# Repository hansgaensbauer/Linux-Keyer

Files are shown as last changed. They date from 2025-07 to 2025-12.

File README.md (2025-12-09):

# Linux-Keyer
An automatic CW keyer build around the [SimpleSBC](https://github.com/hansgaensbauer/SimpleSBC).

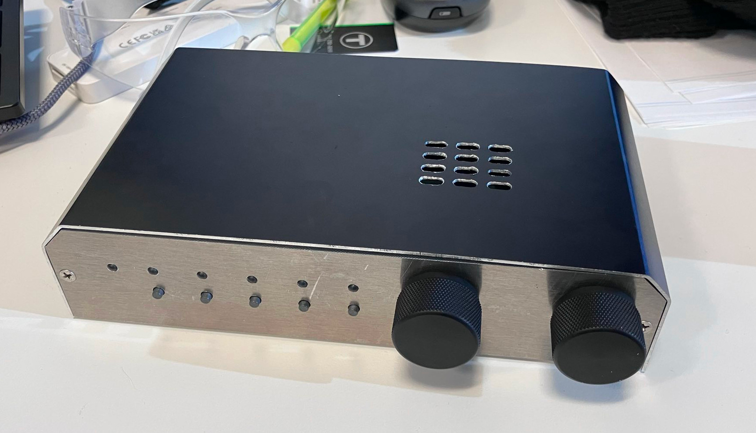
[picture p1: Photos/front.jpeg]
A photo of the keyer


## Features
- 2 Key/Paddle inputs (both keys and paddles supported on both inputs)
- Automatic detection of key wiring
- PTT and Key outputs
- Internal and external speaker support
- Network connectivity (10/100)
- Linux!

<table>
  <tr>
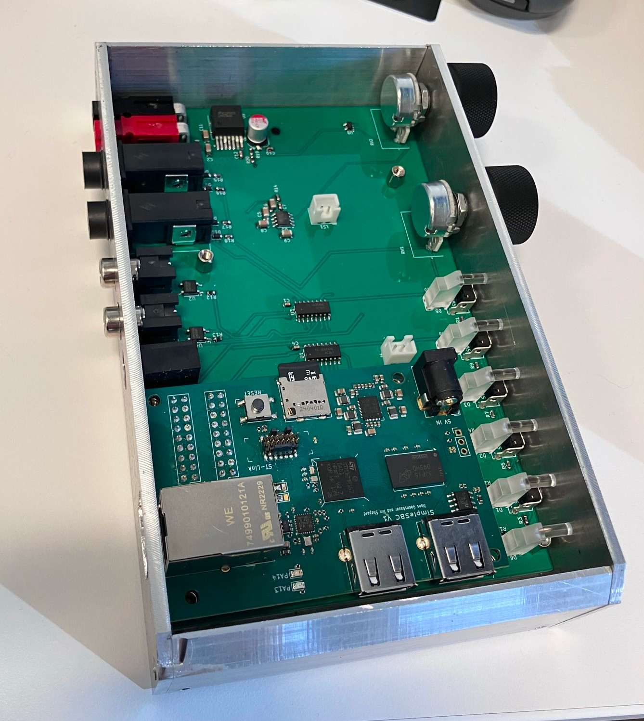
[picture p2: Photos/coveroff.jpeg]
The keyer with the cover off, showing the circuit board
    <td></td>
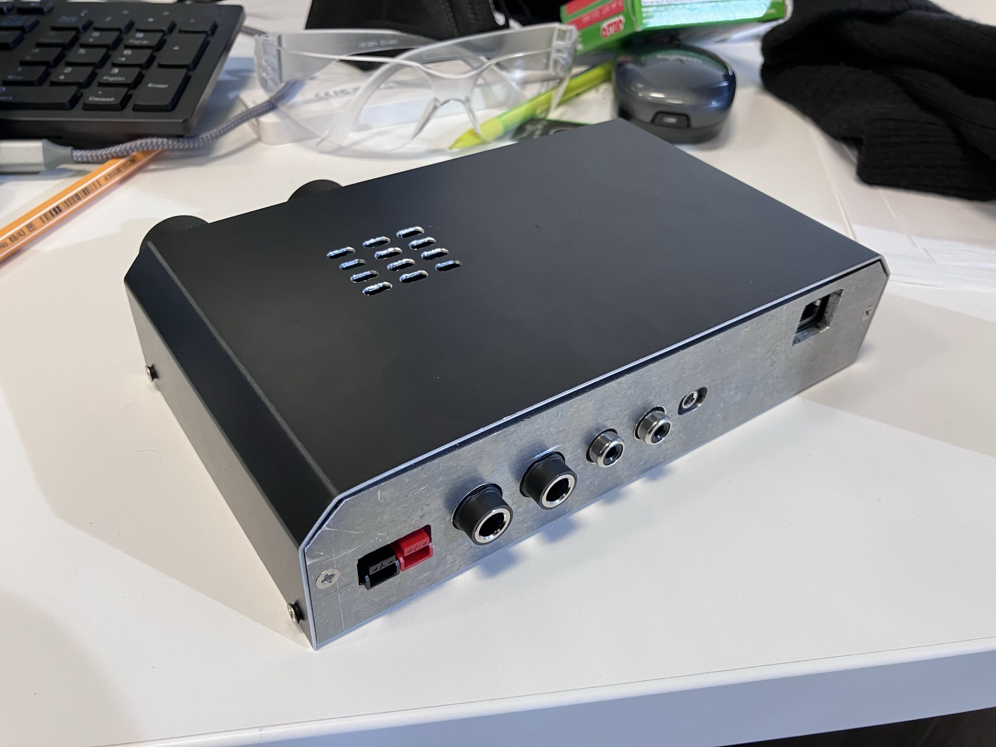
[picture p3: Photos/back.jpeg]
The back side of the keyer
    <td>
  </tr>
</table>

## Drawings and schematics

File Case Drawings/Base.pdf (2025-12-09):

4

3

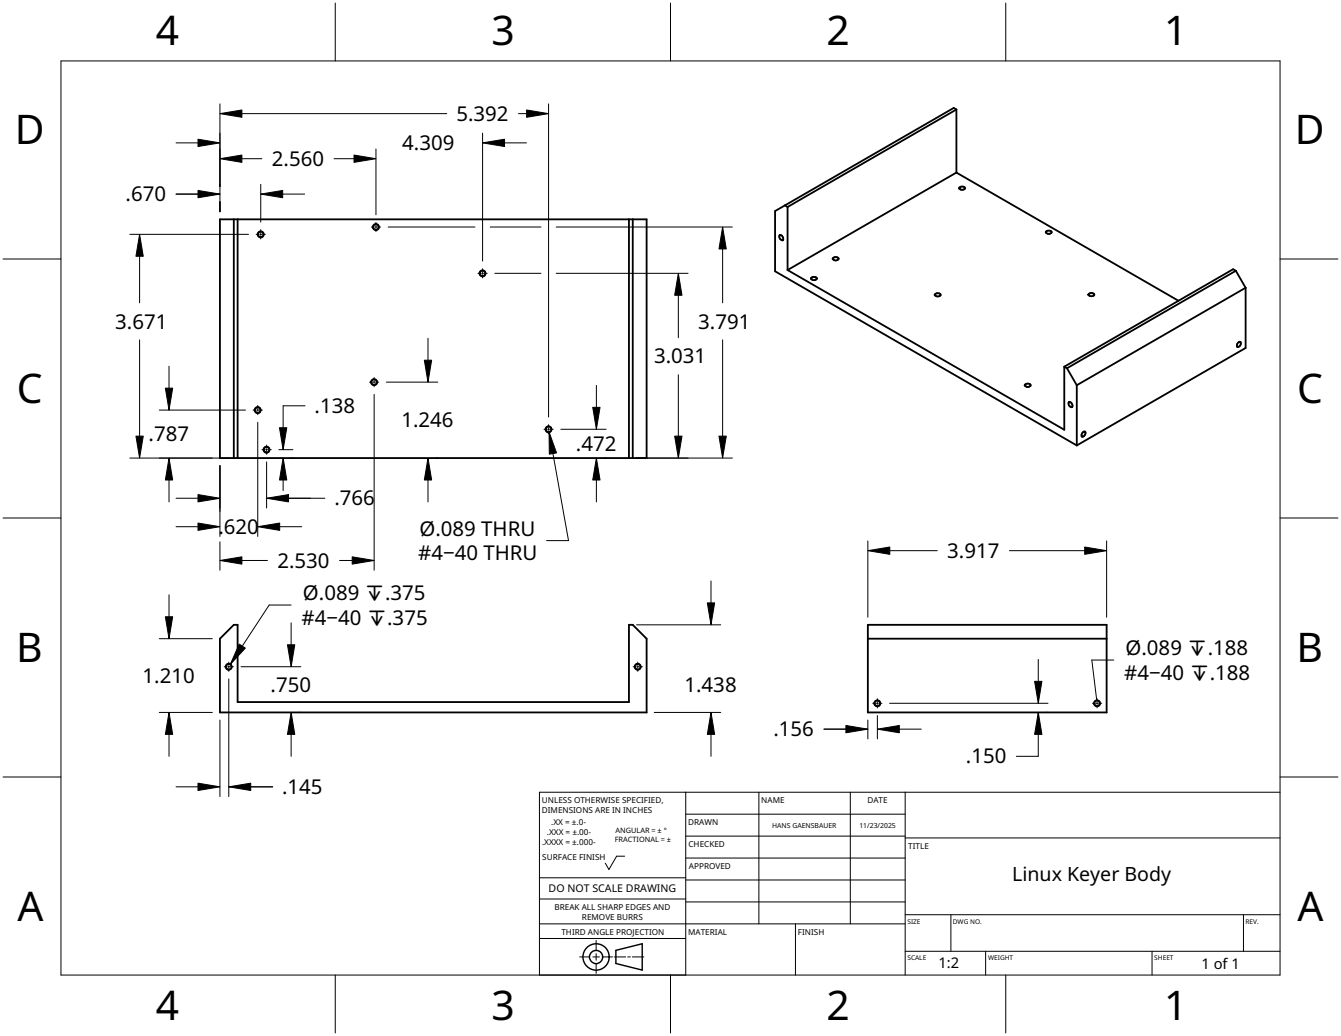
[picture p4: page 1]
MATERIAL; FINISH; Ø.089 THRU #440 THRU

UNLESS OTHERWISE SPECIFIED, DIMENSIONS ARE IN INCHES .XX = ±.0-.XXX = ±.00-ANGULAR = ± ° FRACTIONAL = ± .XXXX = ±.000-SURFACE FINISH | | NAME | DATE

DRAWN | HANS GAENSBAUER | 11/23/2025

CHECKED | | | TITLE Linux Keyer Body

APPROVED

DO NOT SCALE DRAWING
BREAK ALL SHARP EDGES AND
REMOVE BURRS
THIRD ANGLE PROJECTION

SIZE | DWG NO. | REV.

SCALE 1:2 | WEIGHT | SHEET 1 of 1

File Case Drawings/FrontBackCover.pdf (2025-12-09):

4

3

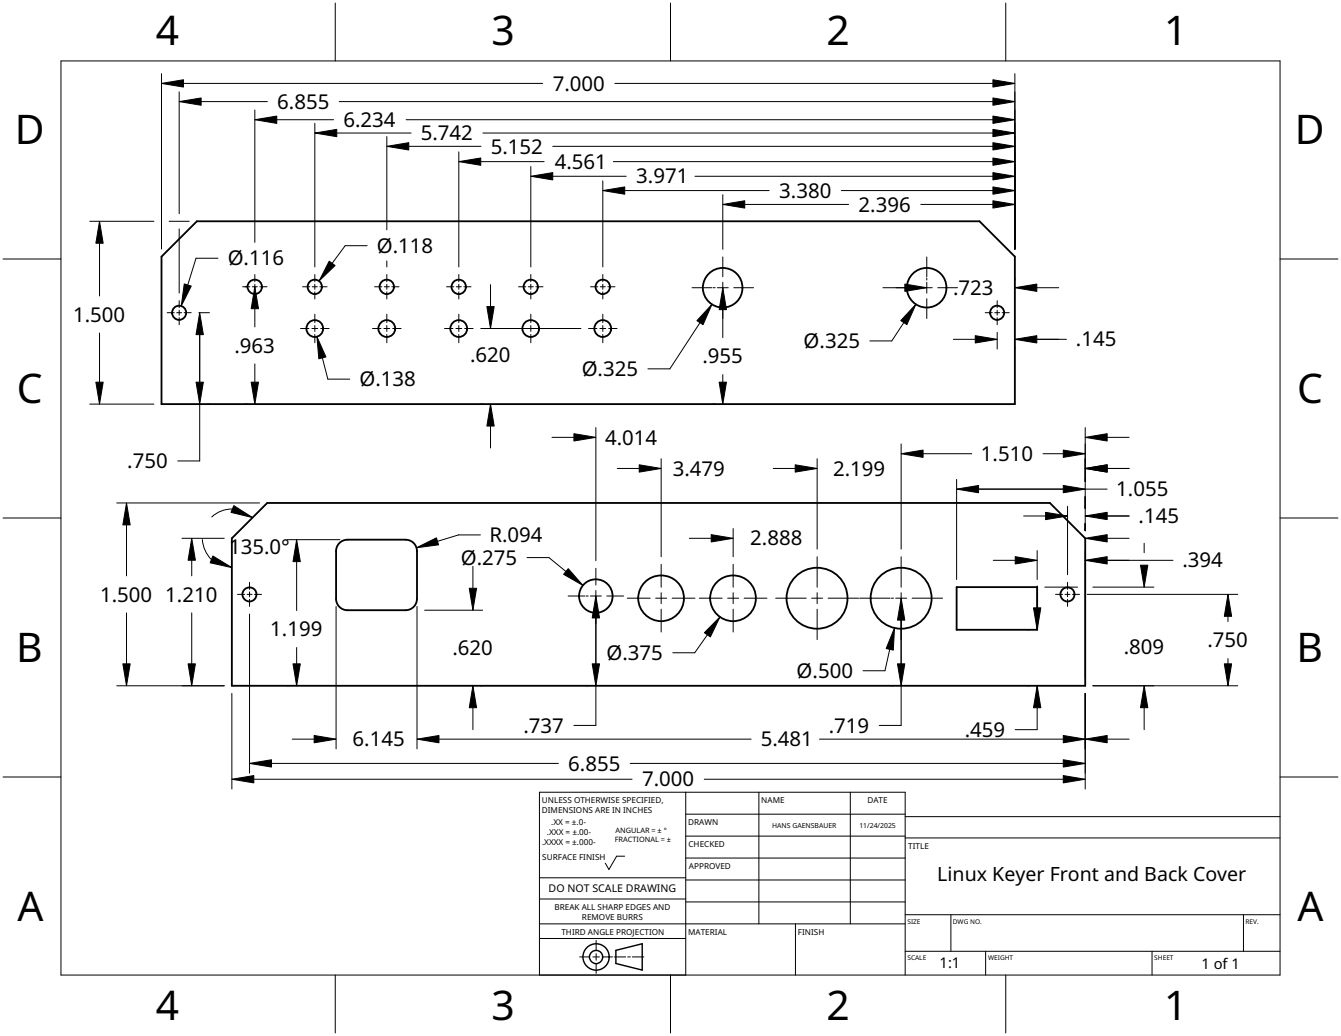
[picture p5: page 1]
MATERIAL; FINISH

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

DRAWN | HANS GAENSBAUER | 11/24/2025

CHECKED | | | TITLE Linux Keyer Front and Back Cover

APPROVED

DO NOT SCALE DRAWING
BREAK ALL SHARP EDGES AND
REMOVE BURRS
THIRD ANGLE PROJECTION

SIZE | DWG NO. | REV.

SCALE 1:1 | WEIGHT | SHEET 1 of 1

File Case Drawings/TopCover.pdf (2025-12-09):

4

3

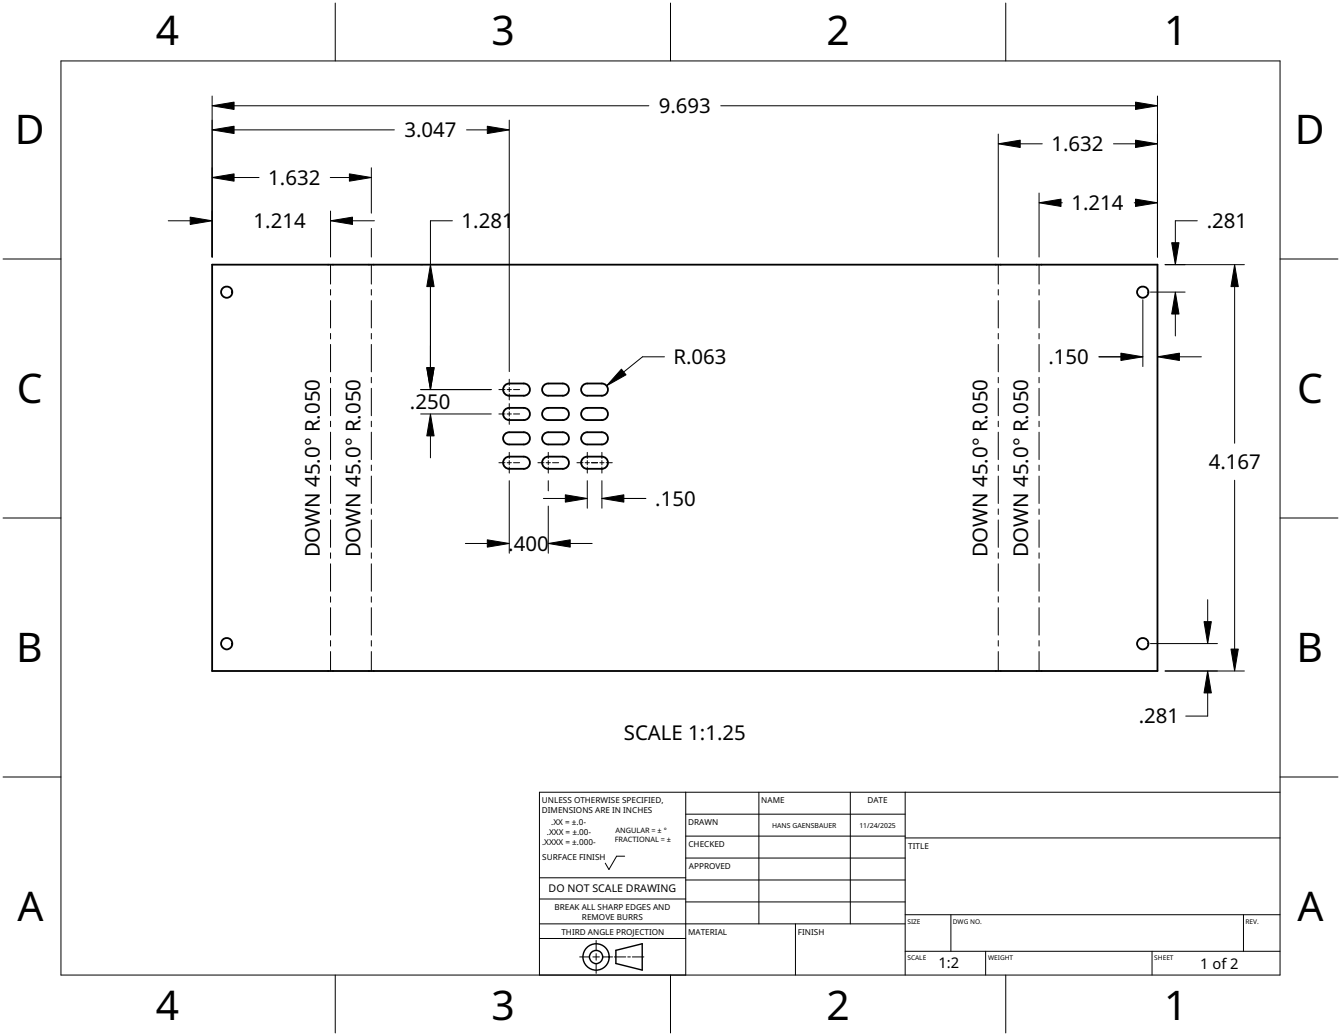
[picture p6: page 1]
MATERIAL; FINISH; SCALE 1:1.25; DOWN 45.0° R.050

UNLESS OTHERWISE SPECIFIED, DIMENSIONS ARE IN INCHES .XX = ±.0-.XXX = ±.00-ANGULAR = ± ° FRACTIONAL = ± .XXXX = ±.000-SURFACE FINISH | | NAME | DATE

DRAWN | HANS GAENSBAUER | 11/24/2025

CHECKED | | | TITLE

APPROVED

DO NOT SCALE DRAWING
BREAK ALL SHARP EDGES AND
REMOVE BURRS
THIRD ANGLE PROJECTION

SIZE | DWG NO. | REV.

SCALE 1:2 | WEIGHT | SHEET 1 of 2

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

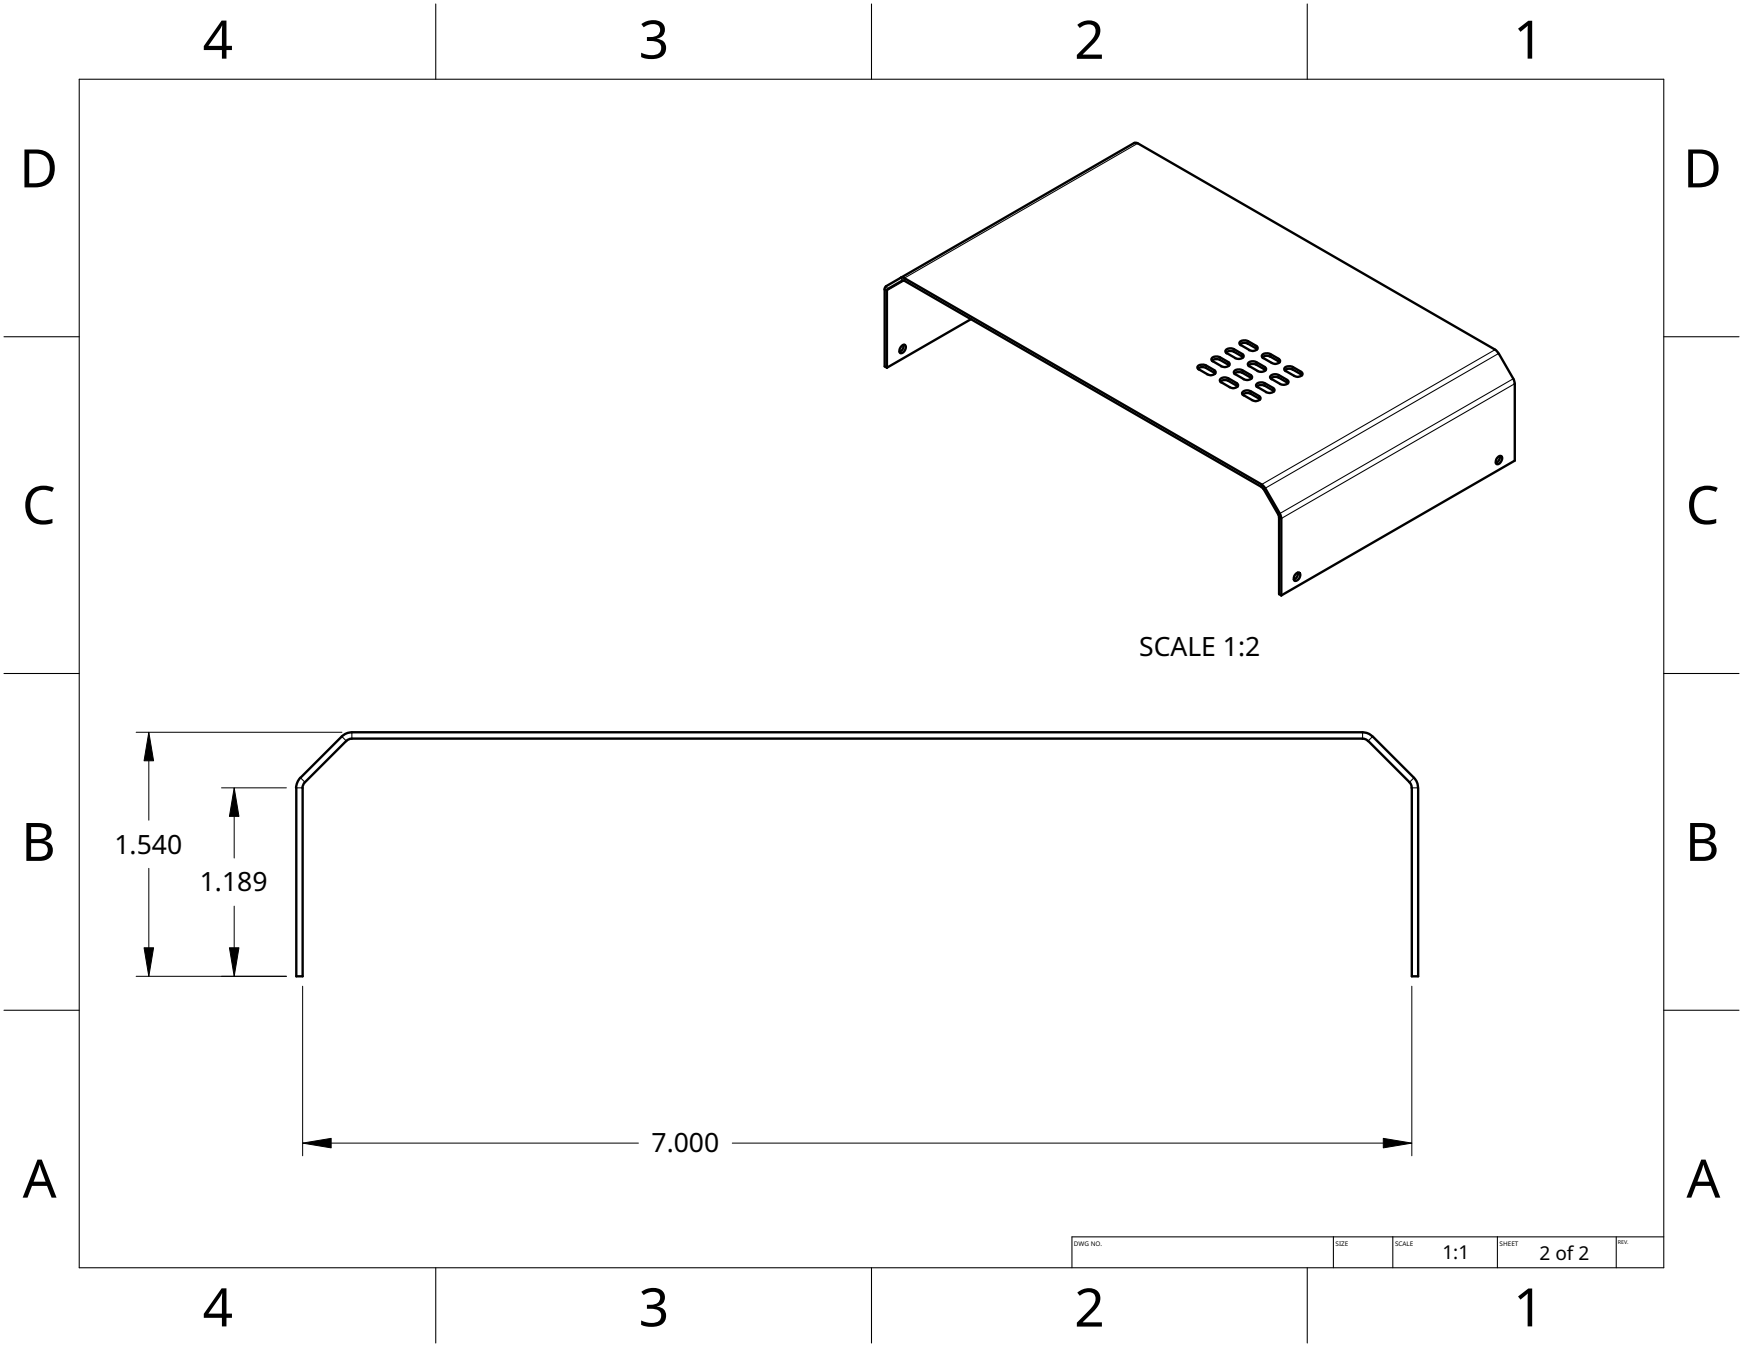
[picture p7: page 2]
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

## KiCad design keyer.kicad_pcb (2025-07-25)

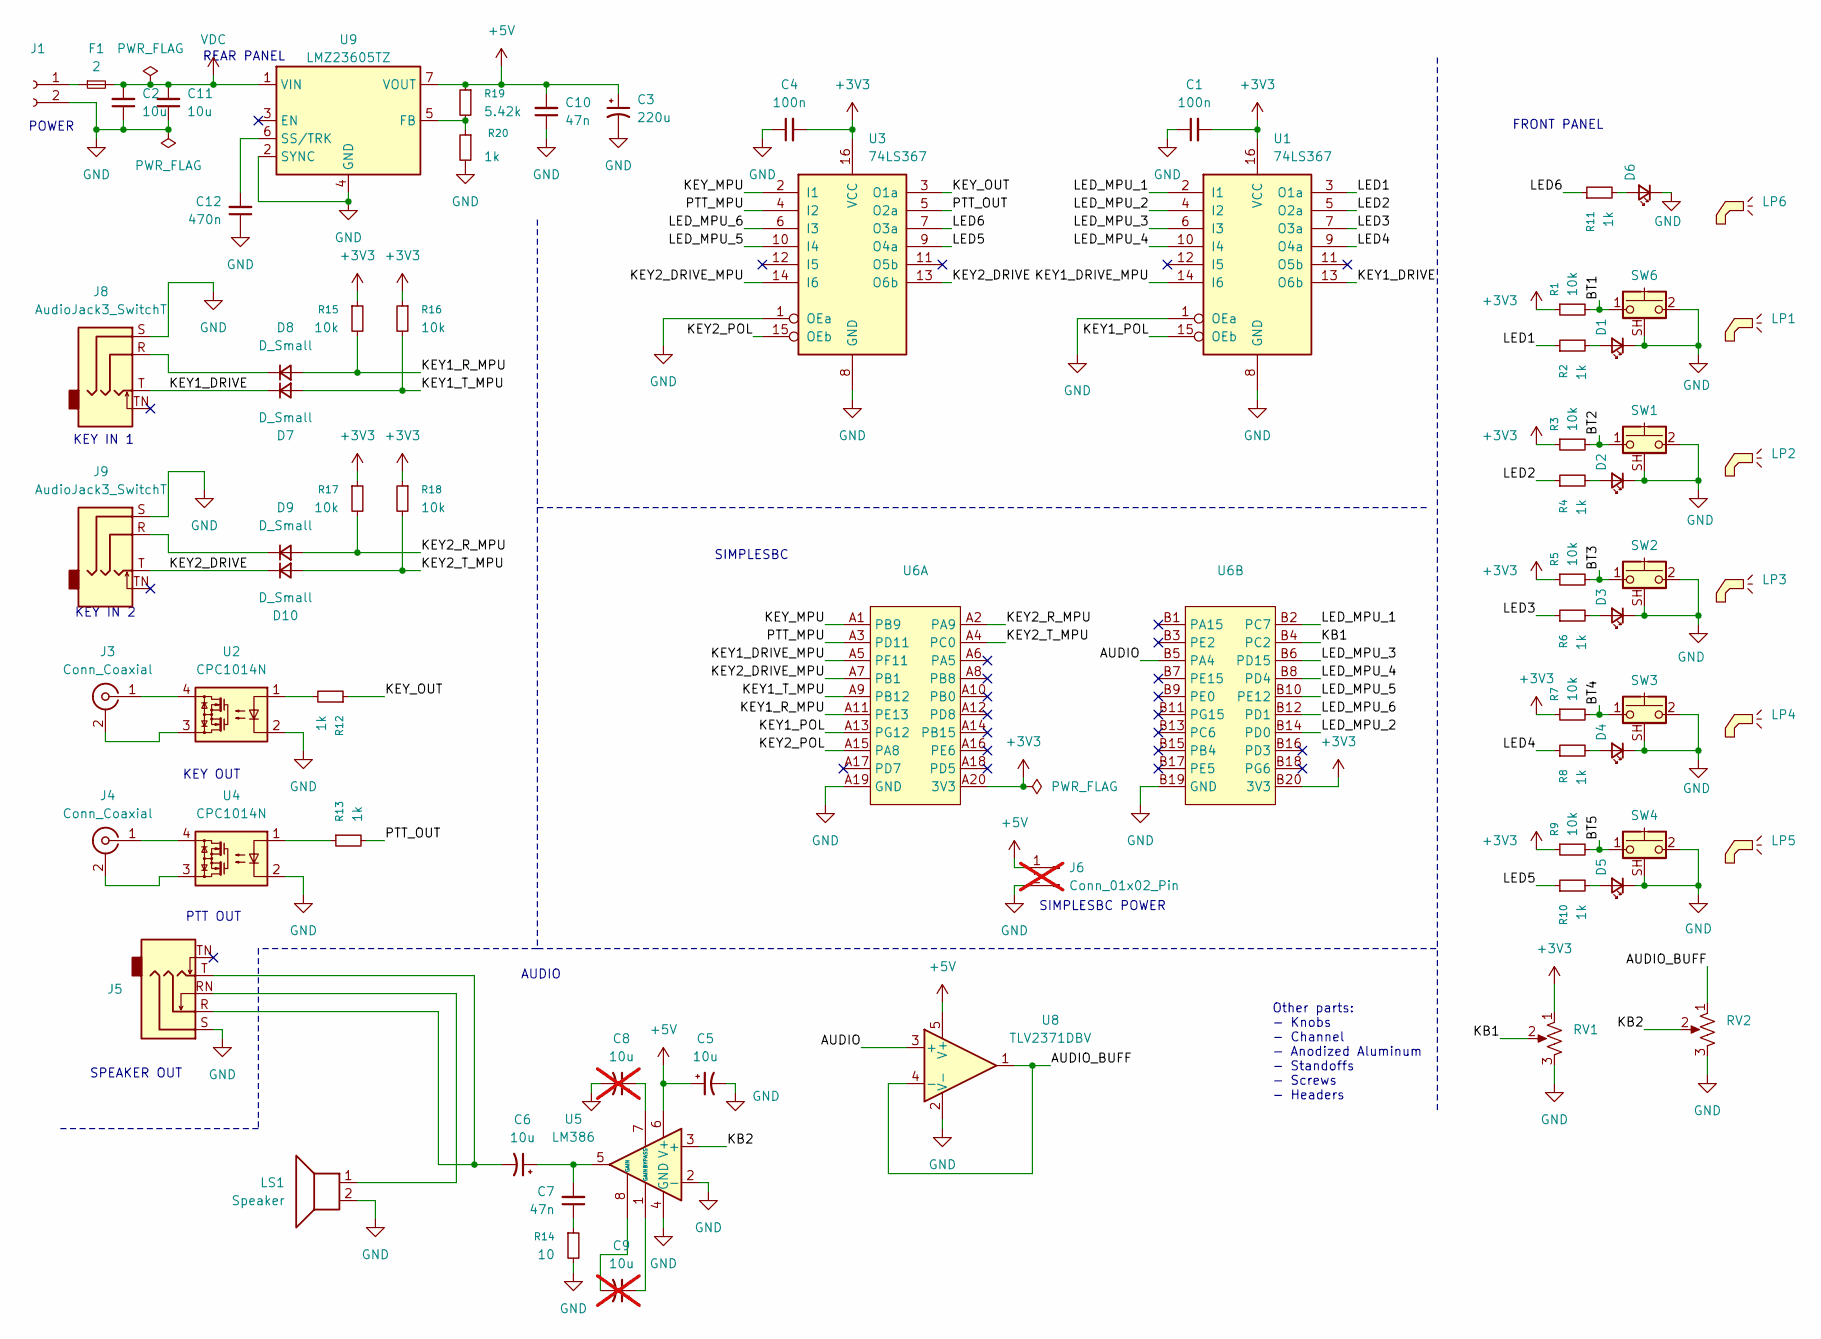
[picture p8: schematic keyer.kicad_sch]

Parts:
C1, C4: 100n; C_0603_1608Metric; Digikey PN 399-C0603C104K5RACTUCT-ND
C2, C5, C6, C11: 10u; C_1206_3216Metric; Digikey PN 1276-1804-1-ND
C3: 220u; CP_Elec_6.3x7.7; Digikey PN 732-8422-1-ND
C7, C10: 47n; C_0603_1608Metric; Digikey PN 490-5854-1-ND
C8, C9: 10u; C_1206_3216Metric; Digikey PN 1276-1804-1-ND; not fitted
C12: 470n; C_0603_1608Metric; Digikey PN 490-3291-1-ND
D1, D2, D3, D4, D5, D6: LED_Small; LED_0603_1608Metric
D7, D8, D9, D10: D_Small; D_SOD-323; Digikey PN 1N4148WXTPMSCT-ND
F1: 2; Fuse_1206_3216Metric; Digikey PN 2315-SBF32202ASTPCT-ND
J1: Conn_01x02_Socket; Powerpole_1x2; Digikey PN 2243-ASMPR45-1X2-RK-ND
J3, J4: Conn_Coaxial; CUI_RCJ-041; Digikey PN CP-1418-ND
J5: AudioJack3_SwitchTR; Jack_3.5mm_CUI_SJ1-3535NG_Horizontal; Digikey PN CP1-3535NG-ND
J6: Conn_01x02_Pin; PinHeader_1x02_P2.54mm_Vertical; not fitted
J8, J9: AudioJack3_SwitchT; SJ-63063B; Digikey PN 2223-SJ-63063B-ND
LP1, LP2, LP3, LP4, LP5, LP6: SLP3-500-450-R; Digikey PN SLP3-500-450-R-ND
LS1: Speaker; JST_XH_B2B-XH-AM_1x02_P2.50mm_Vertical; Digikey PN 2223-CMS-30205-158L120-67-ND
R1, R3, R5, R7, R9, R15, R16, R17, R18: 10k; R_0603_1608Metric; Digikey PN RMCF0603FT10K0CT-ND
R2, R4, R6, R8, R10, R11, R12, R13, R20: 1k; R_0603_1608Metric; Digikey PN 541-1.00KHCT-ND
R14: 10; R_0603_1608Metric; Digikey PN RMCF0603FT10R0CT-ND
R19: 5.42k; R_0603_1608Metric; Digikey PN 2019-RN73R1JTTD5421B25CT-ND
RV1, RV2: R_Potentiometer_US; POT_PTN16-A01120K1B1; Digikey PN 2223-PTN16-A01120K1B1-ND
SW1, SW2, SW3, SW4, SW6: SW_Push_Shielded; 4312560837X6; Digikey PN 431256083716-ND
U1, U3: 74LS367; SOP-16_3.9x9.9mm_P1.27mm; Digikey PN 296-14849-1-ND
U2, U4: CPC1014N; SOP-4_3.8x4.1mm_P2.54mm; Digikey PN CPC1014N-ND
U5: LM386; SOIC-8_3.9x4.9mm_P1.27mm; Digikey PN LM386MX-1/NOPBCT-ND
U6: SimpleSBC; Digikey PN 1212-1247-ND
U8: TLV2371DBV; SOT-23-5; Digikey PN 296-26785-1-ND
U9: LMZ23605TZ; Texas_NDW-7_TabPin4; Digikey PN 296-LMZ23605TZX/NOPBCT-ND

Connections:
+3V3: C1.2, C4.2, R1.1, R3.1, R5.1, R7.1, R9.1, R15.1, R16.1, R17.1, R18.1, RV1.1, U1.16 (VCC), U3.16 (VCC), U6.A20 (3V3), U6.B20 (3V3)
+5V: C3.1, C5.1, C10.2, J6.1, R19.1, U5.6 (V+), U8.5 (V+), U9.7 (VOUT)
/AUDIO: U6.B5 (PA4), U8.3 (+)
/AUDIO_BUFF: RV2.1, U8.1, U8.4 (-)
/BT1: R1.2, SW6.1
/BT2: R3.2, SW1.1
/BT3: R5.2, SW2.1
/BT4: R7.2, SW3.1
/BT5: R9.2, SW4.1
/KB1: RV1.2, U6.B4 (PC2)
/KB2: RV2.2, U5.3 (+)
/KEY1_DRIVE: D7.1 (K), J8.T, U1.13 (O6b)
/KEY1_DRIVE_MPU: U1.14 (I6), U6.A5 (PF11)
/KEY1_POL: U1.15 (OEb), U6.A13 (PG12)
/KEY1_R_MPU: D8.2 (A), R15.2, U6.A11 (PE13)
/KEY1_T_MPU: D7.2 (A), R16.2, U6.A9 (PB12)
/KEY2_DRIVE: D10.1 (K), J9.T, U3.13 (O6b)
/KEY2_DRIVE_MPU: U3.14 (I6), U6.A7 (PB1)
/KEY2_POL: U3.15 (OEb), U6.A15 (PA8)
/KEY2_R_MPU: D9.2 (A), R17.2, U6.A2 (PA9)
/KEY2_T_MPU: D10.2 (A), R18.2, U6.A4 (PC0)
/KEY_MPU: U3.2 (I1), U6.A1 (PB9)
/KEY_OUT: R12.1, U3.3 (O1a)
/LED1: R2.1, U1.3 (O1a)
/LED2: R4.1, U1.5 (O2a)
/LED3: R6.1, U1.7 (O3a)
/LED4: R8.1, U1.9 (O4a)
/LED5: R10.1, U3.9 (O4a)
/LED6: R11.1, U3.7 (O3a)
/LED_MPU_1: U1.2 (I1), U6.B2 (PC7)
/LED_MPU_2: U1.4 (I2), U6.B14 (PD0)
/LED_MPU_3: U1.6 (I3), U6.B6 (PD15)
/LED_MPU_4: U1.10 (I4), U6.B8 (PD4)
/LED_MPU_5: U3.10 (I4), U6.B10 (PE12)
/LED_MPU_6: U3.6 (I3), U6.B12 (PD1)
/PTT_MPU: U3.4 (I2), U6.A3 (PD11)
/PTT_OUT: R13.2, U3.5 (O2a)
GND: C1.1, C2.1, C3.2, C4.1, C5.2, C8.2, C10.1, C11.1, C12.1, D1.1 (K), D2.1 (K), D3.1 (K), D4.1 (K), D5.1 (K), D6.1 (K), J1.2, J5.S, J6.2, J8.S, J9.S, LS1.2, R14.2, R20.2, RV1.3, RV2.3, SW1.2, SW1.SH (B), SW2.2, SW2.SH (B), SW3.2, SW3.SH (B), SW4.2, SW4.SH (B), SW6.2, SW6.SH (B), U1.1 (OEa), U1.8 (GND), U2.2, U3.1 (OEa), U3.8 (GND), U4.2, U5.2 (-), U5.4 (GND), U6.A19 (GND), U6.B19 (GND), U8.2 (V-), U9.2 (SYNC), U9.4 (GND)
unnamed: C6.1, C7.2, U5.5
unnamed: C6.2, J5.R, J5.T
unnamed: C7.1, R14.1
unnamed: C9.1, U5.1 (GAIN)
unnamed: C9.2, U5.8 (GAIN)
unnamed: D1.2 (A), R2.2
unnamed: D2.2 (A), R4.2
unnamed: D3.2 (A), R6.2
unnamed: D4.2 (A), R8.2
unnamed: D5.2 (A), R10.2
unnamed: D6.2 (A), R11.2
unnamed: D8.1 (K), J8.R
unnamed: D9.1 (K), J9.R
unnamed: F1.1, J1.1
unnamed: J3.2 (Ext), U2.3
unnamed: J3.1 (In), U2.4
unnamed: J4.2 (Ext), U4.3
unnamed: J4.1 (In), U4.4
unnamed: J5.RN, LS1.1
unnamed: R12.2, U2.1
unnamed: R13.1, U4.1
unnamed: C8.1, U5.7 (BYPASS)
unnamed: R19.2, R20.1, U9.5 (FB)
unnamed: C12.2, U9.6 (SS/TRK)
VDC: C2.2, C11.2, F1.2, U9.1 (VIN)

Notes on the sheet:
SPEAKER OUT
SIMPLESBC POWER
KEY IN 1
FRONT PANEL
KEY OUT
SIMPLESBC
KEY IN 2
REAR PANEL
POWER
PTT OUT
Other parts: - Knobs - Channel - Anodized Aluminum - Standoffs - Screws - Headers
AUDIO

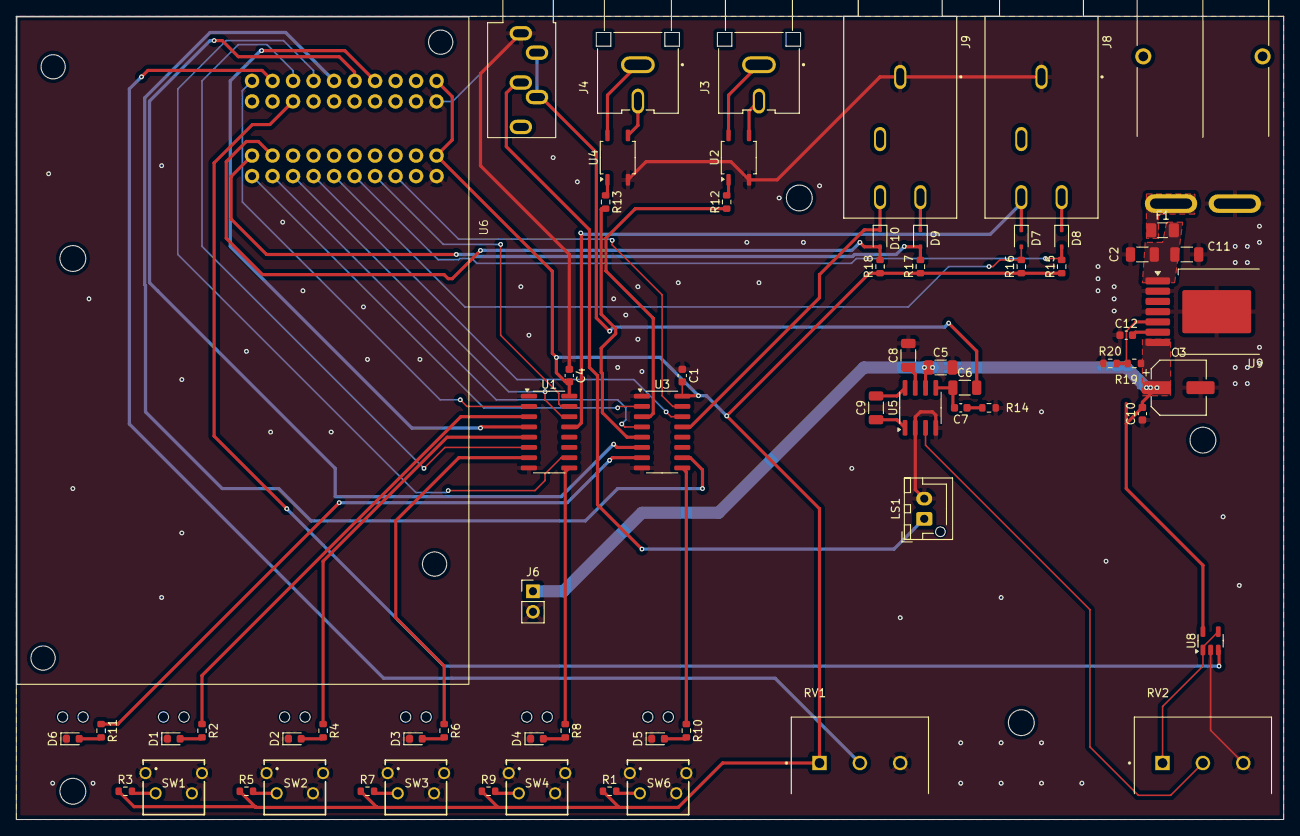
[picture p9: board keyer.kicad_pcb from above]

Board: 2 copper layers, 157.0 x 99.5 mm, 72 parts (0 on the bottom side), 63 nets.
